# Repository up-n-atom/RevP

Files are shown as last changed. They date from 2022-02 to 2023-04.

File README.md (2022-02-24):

# Rev. Probe

## What is RevP?
RevP is a [Black Magic](https://github.com/blackmagic-debug/blackmagic) Probe v2.1 clone updated to include USB-C and high-speed SWO tracing in a keyfob form factor.

## Hardware
### Enclosure
The [enclosure](/Hardware/Enclosure) is designed with [FreeCAD](https://www.freecadweb.org/).

RevPEnclosure

### PCB
The [PCB](/Hardware/PCB) schematic and layout were made with [KiCad](https://www.kicad.org/). The layout replicates a hand-drawn style by utilizing the following plugins: [Teardrops](https://github.com/NilujePerchut/kicad_scripts/tree/master/teardrops) and [RF-Tools round tracks](https://github.com/easyw/RF-tools-KiCAD/tree/master/round_tracks).

RevPPCBFront
RevPPCBBack

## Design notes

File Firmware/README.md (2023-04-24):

## Compile with Fedora Workstation 38

```
toolbox create
toolbox enter
sudo dnf install arm-none-eabi-gcc arm-none-eabi-newlib make gcc dfu-util
git clone --recursive https://github.com/blackmagic-debug/blackmagic.git
cd blackmagic
git apply ../blackmagic-revp.patch
make PROBE_HOST=revp
```

## Bootstrap using BMP and GDB

```
target extended-remote /dev/ttyBmpGdb
monitor swdp_scan
attach 1
monitor option 0x1FFFF804 0x04
exec-file src/blackmagic_dfu.elf
load
compare-sections
kill
```

## Install Firmware Using DFU

```
dfu-util -d 1d50:6018,:6017 -s 0x08002000:leave -D src/blackmagic.bin
```

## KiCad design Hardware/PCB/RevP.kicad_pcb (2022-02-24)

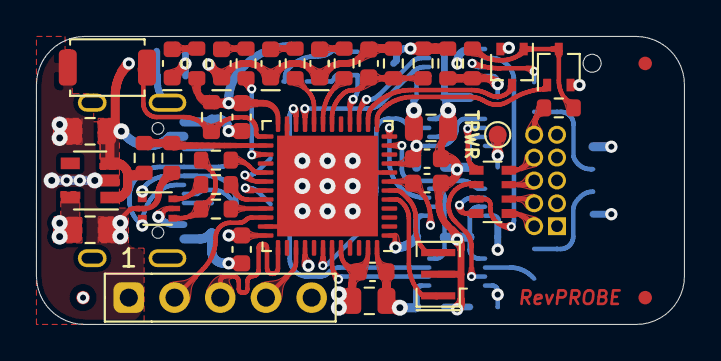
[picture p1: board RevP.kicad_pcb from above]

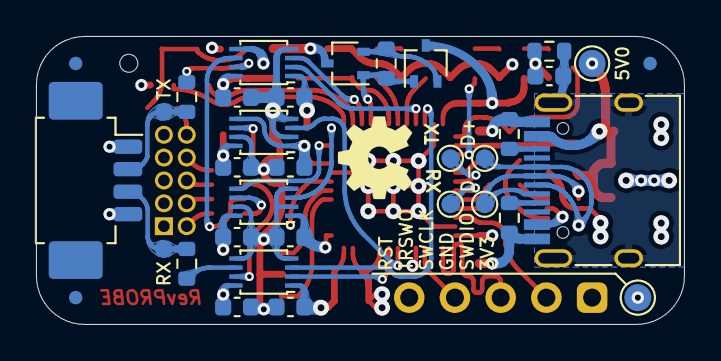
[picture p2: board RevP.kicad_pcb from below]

Board: 4 copper layers, 36.0 x 16.0 mm, 77 parts (34 on the bottom side), 58 nets.

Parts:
C1, C2, C3: C105; C_0805_2012Metric
C4, C6, C7, C8, C9: C104; C_0603_1608Metric
C5: C475; C_0805_2012Metric
C10, C11, C12, C13, C14, C15, C16, C17, C18, C19: C; C_0603_1608Metric
D1, D2, D3, D4: LED; LED_0603_1608Metric
FID1, FID2, FID3, FID4, FID5, FID6: Fiducial; Fiducial_0.75mm_Mask1.5mm
J1: Conn_01x05_Female; PinHeader_1x05_P2.54mm_Vertical
J2: Conn_01x04; Molex_PicoBlade_53261-0471_1x04-1MP_P1.25mm_Horizontal
J3: Conn_02x05_Odd_Even; PinHeader_2x05_P1.27mm_Vertical
J4: USB_C_Receptacle_USB2.0; USB_C_Receptacle_HRO_TYPE-C-31-M-12
Q1, Q2: DMG1012UW; SOT-323_SC-70
Q3, Q4: DMG1013UW; SOT-323_SC-70
R1, R2: 22E; R_0603_1608Metric
R3: 1K5; R_0603_1608Metric
R4, R15: 5K1; R_0603_1608Metric
R5, R6, R7, R8, R9, R10, R11, R12, R13, R14, R20, R21: R; R_0603_1608Metric
R16, R17, R18, R19: 100; R_0603_1608Metric
RN1: 100; R_Array_Convex_4x0603
RX: RX; TestPoint_Pad_D1.0mm
SW1: SW_Push; SW_Push_SPST_NO_Alps_SKRK
TP1: 3V3; TestPoint_Pad_D1.5mm
TP2: D-; TestPoint_Pad_D1.0mm
TP3: D+; TestPoint_Pad_D1.0mm
TP4: 5V; TestPoint_Pad_D1.5mm
TP5: TXD; TestPoint_Pad_D1.0mm
TP6: RXD; TestPoint_Pad_D1.0mm
TPWR: TPWR; TestPoint_Pad_D1.0mm
TX: TX; TestPoint_Pad_D1.0mm
U1: USBLC6-2P6; SOT-666
U2: STM32F103CBUx; QFN-48-1EP_7x7mm_P0.5mm_EP5.6x5.6mm
U3, U5, U7, U9: SN74LVC2T45DCUR; VSSOP-8_2.4x2.1mm_P0.5mm
U11: TLV73333PDBV; SOT-23-5
Y1: 8MHz; Resonator_SMD_muRata_CSTxExxV-3Pin_3.0x1.1mm

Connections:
+3V3: C2.1, C3.1, C4.1, C5.1, C6.1, C7.1, C8.1, C11.1, C13.1, C15.1, C17.1, Q3.3, R5.1, R9.1, TP1.1, U2.1, U2.9, U2.24, U2.36, U2.40, U2.48, U3.1, U3.5, U5.1, U5.5, U7.1, U9.1, U11.5
+5V: C1.1, J4.A4, J4.A9, J4.B4, J4.B9, R10.2, TP4.1, U1.5, U11.1, U11.3
/LED0: R6.1, U2.19
/LED1: R7.1, U2.20
/LED2: R8.2, U2.27
/PWR_BR: Q3.1, Q4.1, R20.1, U2.16
/RST: C9.1, J1.5, U2.7
/SHIELD: C19.2, J4.S1, R21.1
/SWCLK: J1.3, U2.37
/SWDIO: J1.2, U2.34
/TPWR: J2.1, J3.1, Q4.3, R13.1, R19.2
/TRACESWO: J1.4, U2.39
/USB_ATT: R2.2, R3.1, U1.4
/USB_P+: R2.1, U2.33
/USB_P-: R1.1, U2.32
/VBUS: R10.1, R11.2, U2.26
/iRST: Q2.1, U2.13
/iRST_SENSE: Q1.3, U2.14
/iRXD: U2.22, U7.3
/iTCK: U2.15, U5.3
/iTDI: U2.42, U3.3
/iTDO: U2.43, U7.2
/iTMS: U2.12, U9.3
/iTMS_DIR: U2.11, U9.5
/iTXD: U2.21, U5.2
/xRST: Q1.1, Q2.3, R12.2, R18.2
/xRXD: R17.2, U7.6
/xTCK: RN1.3, U5.6
/xTDI: RN1.1, U3.6
/xTDO: RN1.2, U7.7
/xTMS: RN1.4, U9.6
/xTPWR: C12.2, C14.2, C16.2, C18.2, R12.1, R19.1, TPWR.1, U3.8, U5.8, U7.8, U9.8
/xTXD: R16.1, U5.7
GND: C1.2, C2.2, C3.2, C4.2, C5.2, C6.2, C7.2, C8.2, C9.2, C10.2, C11.2, C12.1, C13.2, C14.1, C15.2, C16.1, C17.2, C18.1, C19.1, D1.1, D2.1, D3.1, D4.1, J1.1, J2.4, J3.3, J3.5, J3.9, J4.A1, J4.A12, J4.B1, J4.B12, Q1.2, Q2.2, R4.2, R11.1, R14.2, R15.1, R21.2, SW1.1, U1.2, U2.8, U2.23, U2.35, U2.44, U2.47, U2.49, U3.2, U3.4, U3.7, U5.4, U7.4, U7.5, U9.2, U9.4, U9.7, U11.2, Y1.2
unnamed: C10.1, R13.2, R14.1, U2.18
unnamed: D1.2, R6.2
unnamed: D2.2, R7.2
unnamed: D3.2, R8.1
unnamed: D4.2, R9.2
unnamed: J2.2, R16.2, TP5.1
unnamed: J2.3, R17.1, TP6.1
unnamed: J3.2, RN1.5
unnamed: J3.4, RN1.6
unnamed: J3.6, RN1.7
unnamed: J3.8, RN1.8
unnamed: J3.10, R18.1
unnamed: J4.A5, R4.1
unnamed: J4.A6, J4.B6, TP3.1, U1.3
unnamed: J4.A7, J4.B7, TP2.1, U1.1
unnamed: J4.B5, R15.2
unnamed: Q3.2, Q4.2, R20.2
unnamed: R1.2, U1.6
unnamed: R3.2, U2.29
unnamed: R5.2, SW1.2, U2.25
unnamed: TX.1, U2.30
unnamed: RX.1, U2.31
unnamed: U2.5, Y1.1
unnamed: U2.6, Y1.3
